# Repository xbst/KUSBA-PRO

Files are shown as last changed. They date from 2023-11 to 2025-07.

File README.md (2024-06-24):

# KUSBA Pro (Nozzle KUSBA)
[YouTube Video](https://www.youtube.com/watch?v=ecENeHfXG64)

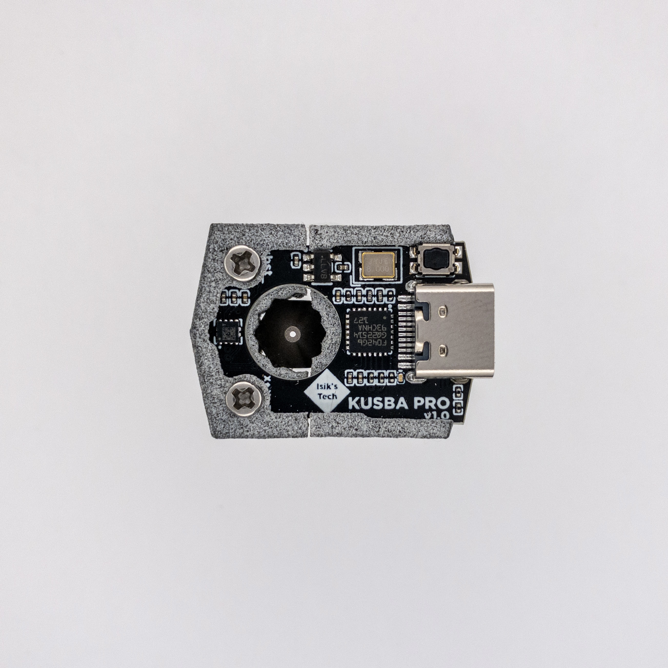
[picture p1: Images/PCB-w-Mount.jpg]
KUSBA Pro


## Purchasing a KUSBA Pro
### United States
- [Isik's Tech](https://store.isiks.tech/products/kusba-pro) (Me)
- [XR Bunker](https://xrbunker.works/products/kusba-pro-nozzle-usb-accelerometer-by-xbst_isik)
### United Kingdom
- [Printy Please](https://www.printyplease.uk/KUSBAPro)
### European Union
- [Lab4450 - Portugal](https://lab4450.com/product/nozzle-kusba-pro-accelerometer/)
### Australia
- [DREMC](https://store.dremc.com.au/products/kusba-pro-usb-accelerometer-for-klipper-adxl345)

This project is licensed under [GPL v3](./LICENSE), meaning vendors are allowed to sell PCBs without paying me. If you'd like to support the development of this and future projects please consider [sponsoring](https://github.com/sponsors/xbst) me on GitHub. You can also subscribe on [Patreon](https://l.isiks.tech/patreon) or [YouTube](https://l.isiks.tech/member).

You can also use the included gerber files to order your own from a PCB manufacturer like [PCBWay](https://www.pcbway.com/setinvite.aspx?inviteid=374841) or [JLCPCB](https://jlcpcb.com/) and you can order the MJF mount from a 3D printing company like [JawsTec](https://www.jawstec.com/3d-printing-service/?aff=6).
<br>

## Instructions

- [LIS2DW KUSBA Pro (v1.0) Firmware Flashing & Usage](./Docs/Firmware.md)
- [ADXL345 KUSBA Pro (v2.0) Firmware Flashing & Usage](./Docs/Firmware-v2.md)
- [Assembling PCB and MJF Mount](./Docs/Mount.md)

## KUSBA v2.4 vs Pro v1.0 vs Pro v2.0

| |KUSBA Pro v2.0|KUSBA Pro v1.0|KUSBA v2.4|
|---|---|---|---|
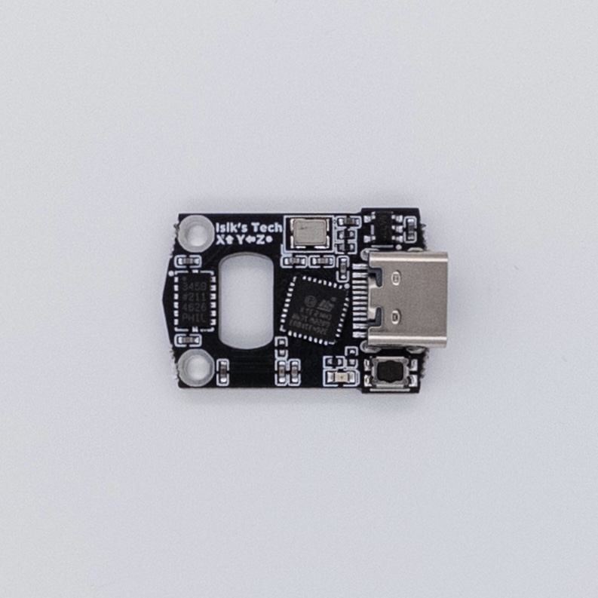
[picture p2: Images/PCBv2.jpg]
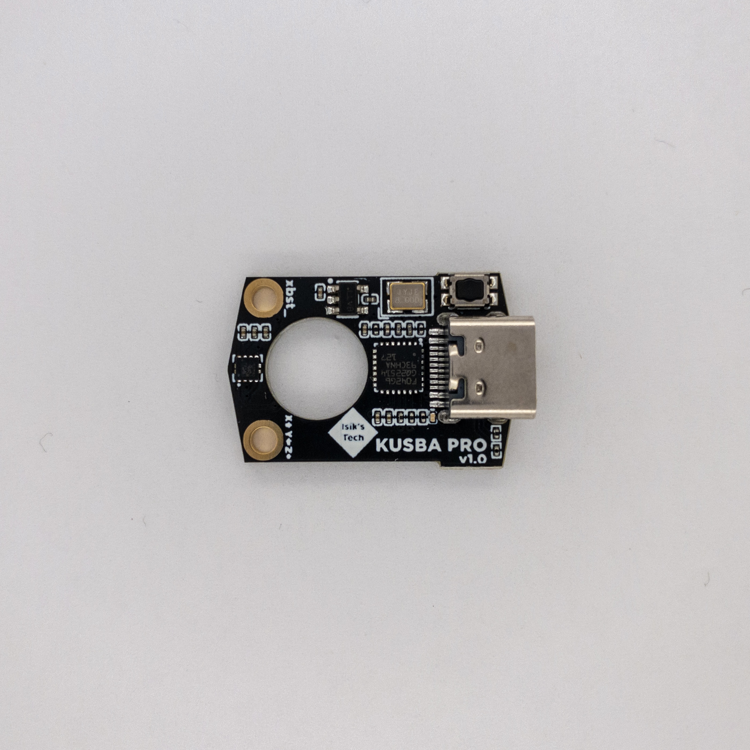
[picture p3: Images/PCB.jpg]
|Picture ||||
|MCU |STM32G431 |STM32F042 |RP2040 |
|Accelerometer|ADXL345 |LIS2DW |ADXL345 |
|3.3V Regulator|LP5907MFX-3.3|LP5907MFX-3.3|AMS1117-3.3|
|Flash |N/A |N/A |W25Q16JVSNIQ|
|Connector |USB C |USB C |USB C |
|Firmware |Klipper |Klipper  |Klipper, Rampon|
|PCB Size |26.0 x 17.6 mm|26.0 x 17.6 mm|34.0 x 25.0 mm|
|Smallest SMD |0402 |0201 |0402 |

## YouTube

I am a YouTube content creator. If you want content about these projects & more, please consider [subscribing to my YouTube channel](https://www.youtube.com/channel/UClAWYmCkHjsbaX9Wz1df2mg).
<br>

If you feel like contributing to the development of this project and other projects like this you can sponsor me on [GitHub](https://github.com/sponsors/xbst), subscribe on [Patreon](https://l.isiks.tech/patreon) or [YouTube](https://l.isiks.tech/member).

## Notes
- Readme files in this repo may contain Amazon Associate, Aliexpress affiliate, PCBWay affiliate, JawsTec affiliate links. I make a comission on qualifying purchases.
- This project does not come with any warranty, if you choose to build/use a PCB manufactured using published files in this repository, you are doing this at your own risk!
- If you want to sell PCBs manufactured using published files in this repository, you are allowed to, and you will not owe me any royalties. **You cannot claim that I endorse the sale**. You can check the license file for more information. However, if you **wish** to give me a share you can sponsor me on [GitHub](https://github.com/sponsors/xbst), subscribe on [Patreon](https://l.isiks.tech/patreon) or [YouTube](https://l.isiks.tech/member).

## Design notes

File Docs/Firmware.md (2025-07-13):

# KUSBA Pro v1 (LIS2DW) Instructions

Note: Make sure to use an up-to-date version of Klipper with LIS2DW accelerometer support.

<br>

<details>
  <summary>Klipper Prep. (enabling resonance testing)</summary>
  
0. Run the following commands in order. This will take some time. (Based on the [official Klipper docs](https://www.klipper3d.org/Measuring_Resonances.html#software-installation))
```
~/klippy-env/bin/pip install -v numpy
sudo apt update
sudo apt install python3-numpy python3-matplotlib libatlas-base-dev
```

</details>

<br>

1. Connect your KUSBA PRO via a USB cable to your Raspberry Pi while holding down the button. The LED on the PCB will turn on.
2. SSH into your Raspberry Pi.
3. Go to the Klipper directory: `cd ~/klipper`
4. Clean remaining files from previous build: `make clean`
5. Choose the options for the build: `make menuconfig`
6. Use these settings:
```
[*] Enable extra low-level configuration options
    Micro-controller Architecture (STMicroelectronics STM32)  --->
    Processor model (STM32F042)  --->
    Bootloader offset (No bootloader)  --->
    Clock Reference (8 MHz crystal)  --->
    Communication interface (USB (on PA9/PA10))  --->
    USB ids  --->
    Optional features (to reduce code size)  --->
()  GPIO pins to set at micro-controller startup (NEW)
```
7. Enter the `Optional features (to reduce code size)` menu. Disable these options:
```
[ ] Support GPIO "bit-banging" devices
[ ] Support LCD devices
[*] Support external sensor devices
[*] Support lis2dw 3-axis accelerometer
[ ] Support software based I2C "bit-banging"
[ ] Support software based SPI "bit-banging"
```
8. Exit by typing `Q`, save by pressing `Y`.
9. Build the firmware: `make`
10. Find the ID of your KUSBA PRO in DFU mode using `lsusb`. It should be the device appearing as `STM Device in DFU mode`.
11. Flash the firmware: `make flash FLASH_DEVICE=1234:5678`. Replace `1234:5678` with the ID you found in the above step.
12. Use `ls /dev/serial/by-id/*` to find the serial address of your KUSBA PRO. It'll start with: `usb-Klipper_stm32f042`
13. [Download the `adxlmcu.cfg` file from this repository](https://github.com/xbst/KUSBA-PRO/blob/master/Firmware/adxlmcu.cfg).
14. Upload the `adxlmcu.cfg` file to your config directory. You can do this on Mainsail/Fluidd etc.
15. Edit the `adxlmcu.cfg` file (in Mainsail/Fluidd). Change the MCU serial address (step 12) and the probe points.
16. Save and close.
17. If your KUSBA PRO isn't assembled follow the [assembly](./Mount.md) doc first.
18. Edit your `printer.cfg` file. Add:
```
[include adxlmcu.cfg]
```
19. Do your input shaper testing. When done comment the include line to disable the KUSBA PRO. (If you don't do this and unplug the KUSBA PRO, Klipper won't work.)
```
# [include adxlmcu.cfg]
```

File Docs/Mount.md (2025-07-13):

# KUSBA Pro Mount Assembly

### Tools Needed
| Tool | Link |
|---|---|
| Phillips #0 Screwdriver |[Amazon US](https://amzn.to/3SBHJuH)|
| Metric Hex 2.5 Driver |[Amazon US](https://amzn.to/473705w)|
| Soldering Iron |[Amazon US](https://amzn.to/3ssW5TC) [Aliexpress](https://s.click.aliexpress.com/e/_DBhTVYR)|

### Parts Needed
| Part | Link |
|---|---|
| KUSBA PRO PCB | [Isik's Tech](https://store.isiks.tech/products/kusba-pro) |
| Front MJF Part | [Jawstec](https://www.jawstec.com/3d-printing-service/?aff=6)|
| Back MJF Part | [Jawstec](https://www.jawstec.com/3d-printing-service/?aff=6)|
| 2x M2x8 Self Tapper Screw  |[Amazon US](https://amzn.to/49wyDp5) [Aliexpress](https://s.click.aliexpress.com/e/_DeJRkcL)|
| 2x M3x12 Screw |[Amazon US](https://amzn.to/3ssW2XW) [Aliexpress](https://s.click.aliexpress.com/e/_DD2Wxyr)|
| 2x M3x5x4 Threaded Insert  |[Amazon US](https://amzn.to/4736XXo) [Aliexpress](https://s.click.aliexpress.com/e/_DkG3oHz)|

### Video
KUSBA PRO Assembly (https://www.youtube.com/watch?v=K55Uk8NYE5w)

### Note
- This guide contains Amazon Associate, Aliexpress affiliate, JawsTec affiliate links. I make a comission on qualifying purchases.

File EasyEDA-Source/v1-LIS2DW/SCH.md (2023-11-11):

Unfortunately the source schematic is lost. I guess I forgot to save it or I overwrote it somehow. Sorry :(

You should be able to use the PCB file for most purposes.

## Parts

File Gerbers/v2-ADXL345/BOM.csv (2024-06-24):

ID | Name | Designator | Footprint | Quantity | Manufacturer Part | Manufacturer | Supplier | Supplier Part | Price
1 | 100nF | C1,C4,C5,C7,C10 | C0402 | 5 | CL05B104KO5NNNC | SAMSUNG(三星) | LCSC | C1525 | 0.001
2 | 1uF | C2,C3,C6 | C0402 | 3 | CL05A105KA5NQNC | SAMSUNG(三星) | LCSC | C52923 | 0.003
3 | 30pF | C8,C9 | C0402 | 2 | 0402CG300J500NT | FH(风华) | LCSC | C1570 | 0.001
4 | 10kΩ | R1 | R0402 | 1 | 0402WGF1002TCE | UNI-ROYAL(厚声) | LCSC | C25744 | 0.001
5 | 5.1kΩ | R2,R4 | R0402 | 2 | 0402WGF5101TCE | UNI-ROYAL(厚声) | LCSC | C25905 | 0.001
6 | 1.5kΩ | R3 | R0402 | 1 | 0402WGF1501TCE | UNI-ROYAL(厚声) | LCSC | C25867 | 0.001
7 | 10Ω | R5 | R0402 | 1 | 0402WGF100JTCE | UNI-ROYAL(厚声) | LCSC | C25077 | 0.001
8 | LED-0603_B | LED | LED0603_BLUE | 1 | 19-217/BHC-ZL1M2RY/3T | EVERLIGHT(台湾亿光) | LCSC | C72041 | 0.021
9 | ADXL345BCCZ-RL7 | U1 | LGA-14_L5.0-W3.0-P0.80-BL | 1 | ADXL345BCCZ-RL7 | ADI | LCSC | C9667 | 1.842
10 | STM32G431KBU3 | U2 | UFQFPN-32_L5.0-W5.0-P0.50-BL-EP3.5 | 1 | STM32G431KBU3 | ST(意法半导体) | LCSC | C1341901 | 2.631
11 | USB3.1C16PFSMT | USBC | USB-C-SMD_TYPE-C-USB-17 | 1 | - | LCSC | LCSC | C167321 | 0.35
12 | EVPAA202K | BOOT | KEY-SMD_4P-L3.5-W2.9-P1.48-LS4.3-TL | 1 | EVPAA202K | PANASONIC(松下) | LCSC | C79147 | 0.32
13 | LP5907MFX-3.3/NOPB | U3 | SOT-23-5_L3.0-W1.7-P0.95-LS2.8-BR | 1 | LP5907MFX-3.3/NOPB | TI(德州仪器) | LCSC | C80670 | 0.141
14 | 8MHz | X1 | CRYSTAL-SMD_4P-L3.2-W2.5-BL-2 | 1 |  | JYJE(晶友嘉) | LCSC | C2924619 | 0.195

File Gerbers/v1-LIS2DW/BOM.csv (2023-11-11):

ID | Name | Designator | Footprint | Quantity | Manufacturer Part | Manufacturer | Supplier | Supplier Part | Price
1 | EVPAA202K | BOOT | KEY-SMD_4P-L3.5-W2.9-P1.48-LS4.3-TL | 1 | EVPAA202K | PANASONIC(松下) | LCSC | C79147 | 0.356
2 | 100nF | C1,C4,C5,C7,C10,C11 | C0201 | 6 |  | FH(风华) | LCSC | C66938 | 0.001
3 | 1uF | C2,C3,C6 | C0201 | 3 |  | Walsin(华新科) | LCSC | C295898 | 0.004
4 | 30pF | C8,C9 | C0201 | 2 |  | FH(风华) | LCSC | C2762281 | 0.002
5 | XL-0201UBC | LED | LED-SMD_L0.7-W0.4-RD_BLUE | 1 |  | XINGLIGHT(成兴光) | LCSC | C3646921 | 0.1
6 | 10kΩ | R1 | R0201 | 1 |  | YAGEO(国巨) | LCSC | C143978 | 0.004
7 | 5.1kΩ | R2,R7 | R0201 | 2 |  | YAGEO(国巨) | LCSC | C274341 | 0.001
8 | 27.4Ω | R3,R4 | R0201 | 2 |  | UNI-ROYAL(厚声) | LCSC | C423620 | 0.001
9 | 10Ω | R5 | R0201 | 1 |  | RALEC(旺诠) | LCSC | C102687 | 0.001
10 | 1.5kΩ | R6 | R0201 | 1 |  | PANASONIC(松下) | LCSC | C713487 | 0.011
11 | LIS2DW12TR | U1 | LGA-12_L2.0-W2.0-P0.50-BL | 1 |  | ST(意法半导体) | LCSC | C189624 | 0.447
12 | STM32F042G6U6 | U2 | UFQFPN-28_L4.0-W4.0-P0.50-BL | 1 |  | ST(意法半导体) | LCSC | C961597 | 1.184
13 | LP5907MFX-3.3/NOPB | U3 | SOT-23-5_L3.0-W1.7-P0.95-LS2.8-BR | 1 | LP5907MFX-3.3/NOPB | TI(德州仪器) | LCSC | C80670 | 0.178
14 | 8MHz | X1 | CRYSTAL-SMD_4P-L3.2-W2.5-BL-2 | 1 |  | JYJE(晶友嘉) | LCSC | C2924619 | 0.24
15 | USB3.1C16PFSMT | USBC1 | USB-C-SMD_TYPE-C-USB-17 | 1 | - | LCSC | LCSC | C167321 | 0.358

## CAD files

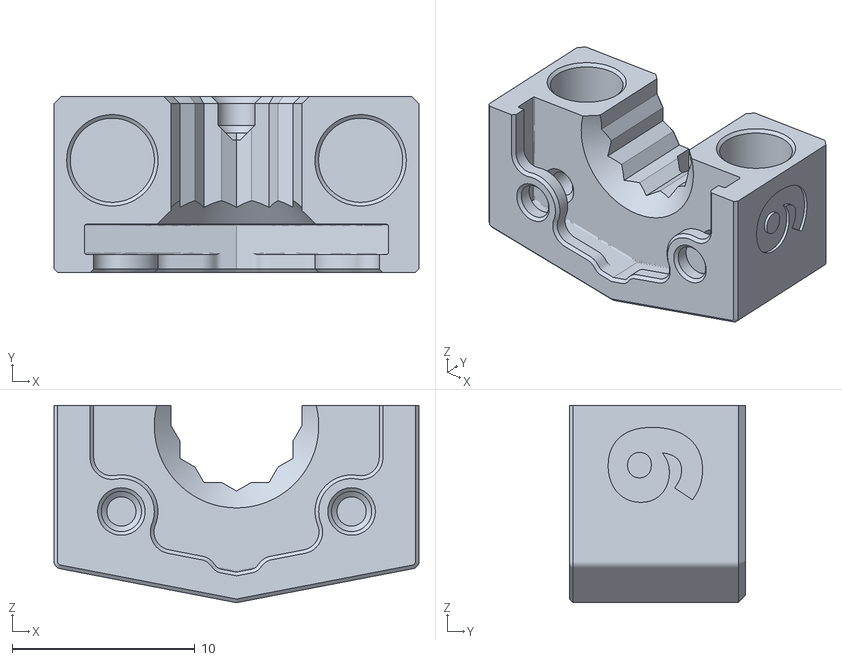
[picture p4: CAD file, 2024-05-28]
Mount/CHT/Back.stl
20.0 x 9.65 x 10.8

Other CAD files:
Mount/Standard/Back.stl

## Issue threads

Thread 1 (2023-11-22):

Explain what KUSBA is

jueank, 2023-11-22:
I just navigated to this Github project. There is not a single sentence explaining what this is about to begin with. I have no idea what KUSBA is. Or what's the difference between the 2 versions shown in the table.

xbst, 2023-11-23:
KUSBA stands for Klipper USB Accelerometer. It's an USB accelerometer for measuring resonances for Klipper's input shaping. In terms of the components on the PCB, it's an accelerometer and an MCU running Klipper firmware (or Rampon on KUSBA v2), connected to the computer running Klipper with an USB cable.
KUSBA v2 has an ADXL345 accelerometer and a RP2040 MCU, running Klipper or Rampon firmware. It's primarily designed for mounting somewhere on a 3D printer's toolhead. It can be nozzle-mounted too but it's difficult.
KUSBA PRO addresses this by having an integrated, MJF-printed, clamp-style nozzle mount. It also uses different (arguably slightly superior) components for MCU and acclerometer. (RP2040 and ADXL345 vs STM32F042 and LIS2DW)

jueank, 2023-12-01:
Thank you for the explanation. I would recommend to poste this into the README.md

Closed 2023-12-16.

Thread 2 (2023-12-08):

Unable to compile klipper due to lack of space in rom

staticanime, 2023-12-08:
Getting the following when trying to compile klipper for the KUSBA PRO

make KCONFIG_CONFIG=klipper-xbst-kusba.config
```
Version: v0.12.0-0-g0d67d9c4
  Preprocessing out/src/generic/armcm_link.ld
  Linking out/klipper.elf
/usr/lib/gcc/arm-none-eabi/10.3.1/../../../arm-none-eabi/bin/ld: out/klipper.elf section `.text' will not fit in region `rom'
/usr/lib/gcc/arm-none-eabi/10.3.1/../../../arm-none-eabi/bin/ld: region `rom' overflowed by 532 bytes
collect2: error: ld returned 1 exit status
make: *** [Makefile:72: out/klipper.elf] Error 1
```

Contents of the **make menuconfig KCONFIG_CONFIG=klipper-xbst-kusba.config** file:
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

Closed 2023-12-08.

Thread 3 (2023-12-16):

Firmware update | usb pins

Valevach, 2023-12-16:
Hi!
Im trying to update firmware on STM32F042 using instruction at
https://github.com/xbst/KUSBA-PRO/blob/master/Docs/Firmware.md

After successful flashing process via DFU, I didn`t receive any device at lsusb.
Even after pull-out the wire ang plug again - no new messages at dmesg

I see there is menuconfig configuration line like:
Communication interface (USB (on PA9/PA10))  --->

But I have only option USB (on PA11/PA12)
Pins are mismatched? Also i have option Serial (on USART1 PA10/PA9)

How to build it?

xbst, 2023-12-16:
Make sure to enable low level options. The correct USB pins will be added to the list.
________________________________
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

Valevach, 2023-12-16:
Oh thank you!

Also this setting required:
    Clock Reference (Internal clock)  --->

Now it looks work.

Closed 2023-12-16.

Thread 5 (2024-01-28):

Standard mount has too thin walls.

VovyCZ, 2024-01-28:
The standard mount has too thin walls for M3 screws and threaded inserts. It doesn't slice, print and use very well.

xbst, 2024-01-28:
It's not designed for FDM printing, prints fine with MJF.

Closed 2024-01-28.

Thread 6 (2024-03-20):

Order PCB issue

HangryPanda, 2024-03-20:
Hi, I attempted to place an order through PCBWay and the engineer replied with the following:

 for black soldermask, we need the IC spacing to be 0.22 mm at least, otherwise the soldermask bridge can not be produced.  Do you need soldermsk bridge?
If so, pls enlarge the IC spacing to be 0.22mm at least, then send us the new file back.
If not, we will make the whole area exposed with soldermask opening where the IC spacing is not large enough.  In this case there is no soldermask ink between IC pads, and it's not good for soldering. Is it ok for you?

I have no experience whatsoever designing/editing PCBs. What should I do?

Thanks. I would have purchased from you, but you're sold out.
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

xbst, 2024-03-20:
This PCB is a tricky one for PCB manufacturers to make. I wanted to make the PCB as small as possible, so I used small chips and 0201 passives. This requires better tolerances on the PCB.

There's no way to enlarge IC pin spacing, that's the spacing of the pins of that chip. You can't just make that larger without changing the chip. Removing the soldermask _might_ work, but it's risky. Soldermask between those pads helps prevent bridged pads (shorts).

They may have a more expensive service with better tolerances. Or they might be able to make them with a different color soldermask. If not, I wouldn't order it. Other PCB manufacturers might be able to do it.

XR Bunker is sold out but I have them in stock (except Revo size): https://store.isiks.tech/products/kusba-pro-1

HangryPanda, 2024-03-21:
Thanks for replying so quickly! I just placed my order on your website. I wonder if the color of the soldermask affects the tolerances. I chose black but perhaps the default color might work? I'll ask them if only to satisfy my own curiosity.

HangryPanda, 2024-03-24:
Here's the response from PCBWay

`"1) There's no influence on tolerance if we change the solder mask color. It's suggested changing to green as we need min 0.19mm IC spacing for this color. Is it OK for you?"`

I'm going to interpret this as yes it does influence the tolerances. So choose green if there are tight tolerances without needing to pay extra for a high accuracy build process*

*to a degree.

Closed 2024-03-24.

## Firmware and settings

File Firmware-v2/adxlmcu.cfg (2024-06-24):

[mcu adxl]
serial: /dev/serial/by-id/xxx
# Edit the above line with the correct serial address. Use "ls /dev/serial/by-id/*" to find the MCU serial address.

[adxl345]
cs_pin: adxl:PA4
spi_bus: spi1

[resonance_tester]
accel_chip: adxl345
probe_points:
   0,0,0
# Edit the above line with the correct probe points location. I recommend the center of your bed for X & Y, 20 for Z.
# For 350 mm printers: 175,175,20
# For 300 mm printers: 150,150,20
# For 250 mm printers: 125,125,20
# For 120 mm printers: 60,60,20

# More info: https://www.klipper3d.org/Config_Reference.html#adxl345

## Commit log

2023-11-11 Source and gerber files
    [BOM.csv, PNP.csv]
2023-11-17 Move v6 mount
    [Back.stl]
2023-12-16 CHT mounts
    [Back.stl, Mount&PCB.f3d]
2023-12-19 Update README.md
    Added Printy Please store as a UK supplier.
2024-05-28 New Mounts
    [Back.stl]
2024-06-23 v2 files
    [BOM.csv, PNP.csv]
